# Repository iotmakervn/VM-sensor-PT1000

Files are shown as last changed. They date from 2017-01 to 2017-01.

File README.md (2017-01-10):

# VM-sensor-PT1000

## Hardware

### Schematics

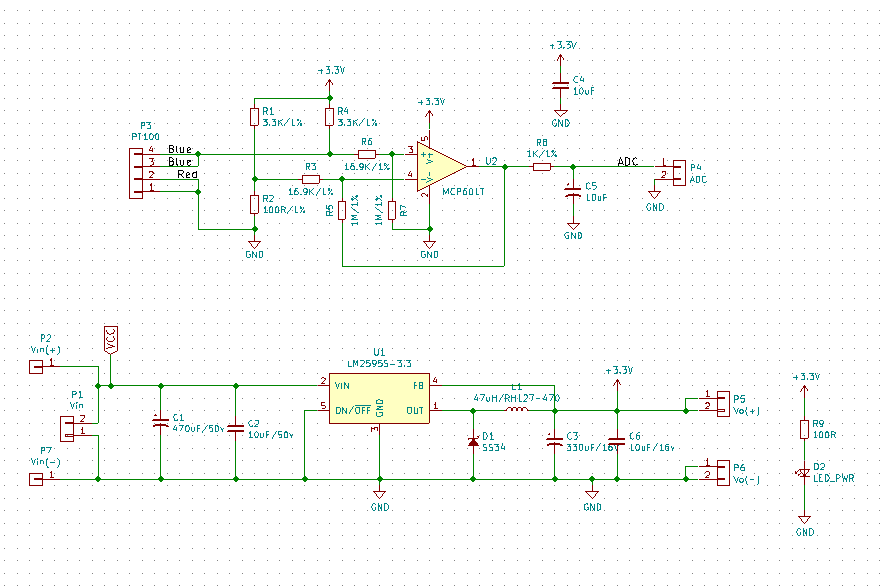
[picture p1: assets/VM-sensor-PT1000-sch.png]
VM-sensor-PT1000 Schematic


### PCB Layout

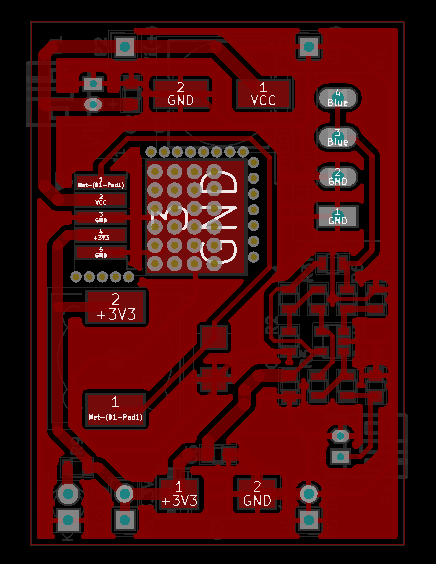
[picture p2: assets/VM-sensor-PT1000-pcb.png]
VM-sensor-PT1000 PCB


### 3D

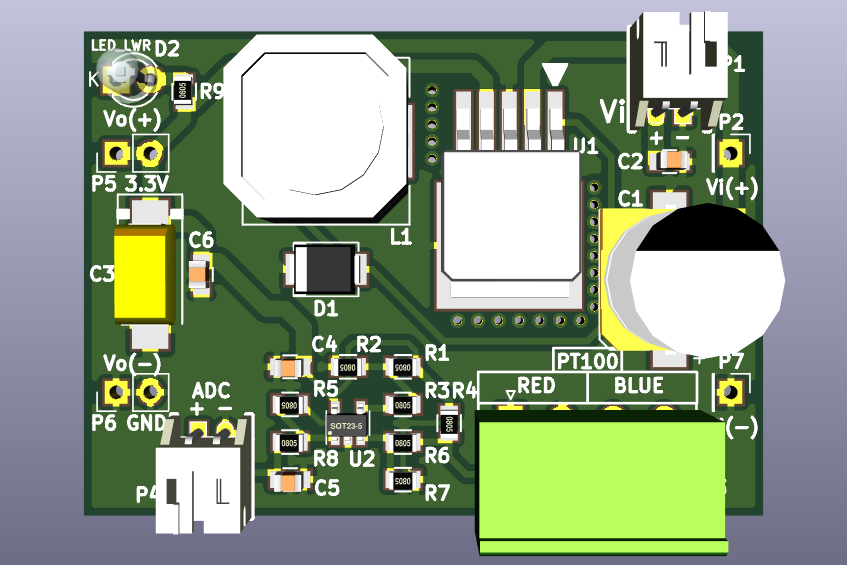
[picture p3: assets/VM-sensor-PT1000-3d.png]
VM-sensor-PT1000 3D


### Gerber

[Download](./assets/gerber.zip)

### BOM 
| Id | Designator  | Package | Quantity | Designation |
|----|---|---|---|---|
| 1  | U1 | TO-263-5Lead | 1 | LM2595S-3.3 |
| 2  | U2 | SOT-23-5 | 1 | MCP601T |
| 3  | D1 | do214aa-g | 1 | SS34 |
| 4  | D2 | LED-3MM | 1 | LED_Small |
| 5  | L1 | Choke_SMD_12x12mm_h8mm | 1 | 47uH/RH127-470 |
| 6  | C1 | c_elec_10x10.5 Aluminum | 1 | 470uF/50v |
| 7  | C3 | Tantalum_Case-D_EIA-7343-31_Hand | 1 | 330uF/16V |
| 8  | C4,C5,C6 | C_0805 | 3 | 10uF/16v |
| 9  | C2 | C_0805 | 1 | 10uF/50v |
| 10 | R1,R4 | R_0805 | 2 | 3.3K/1% |
| 11 | R2 | R_0805 | 1 | 100R/1% |
| 12 | R3,R6 | R_0805 | 2 | 16.9K/1% |
| 13 | R5,R7 | R_0805 | 2 | 1M/1% |
| 14 | R8 | R_0805 | 1 | 1K/1% |
| 15 | R9 | R_0805 | 1 | 100R |
| 16 | P3 | Domino-PT100.pretty | 1 | 4P-3.81 Pluggable Terminal Block |
| 17 | P2,P5,P6,P7 | Pin_Header_Straight_1x01_Pitch2.54mm | 4 | Male header, Pitch: 2.54MM |
| 18 | P4,P1 | s2b-ph-kl | 2 | WB2F-L40P2.54 |

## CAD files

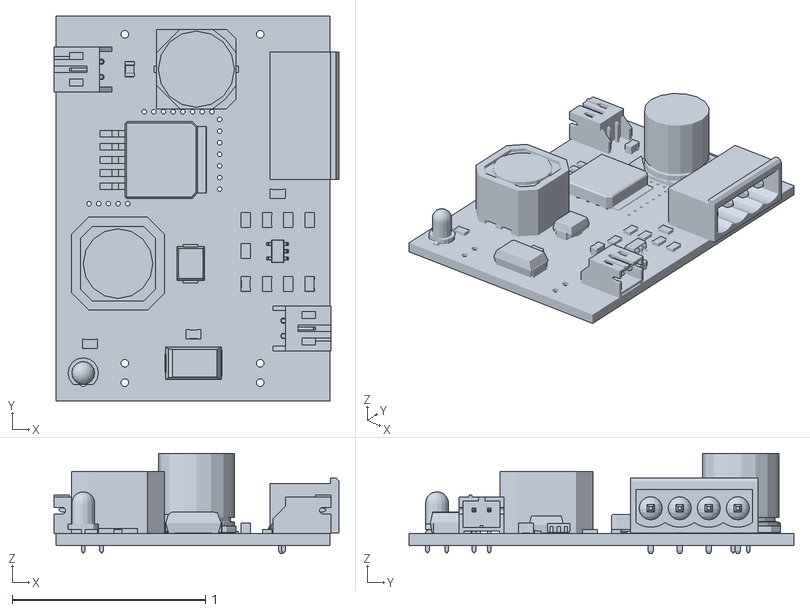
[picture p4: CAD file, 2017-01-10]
assets/VM-sensor-PT1000-3d.stl
1.47 x 1.99 x 0.517

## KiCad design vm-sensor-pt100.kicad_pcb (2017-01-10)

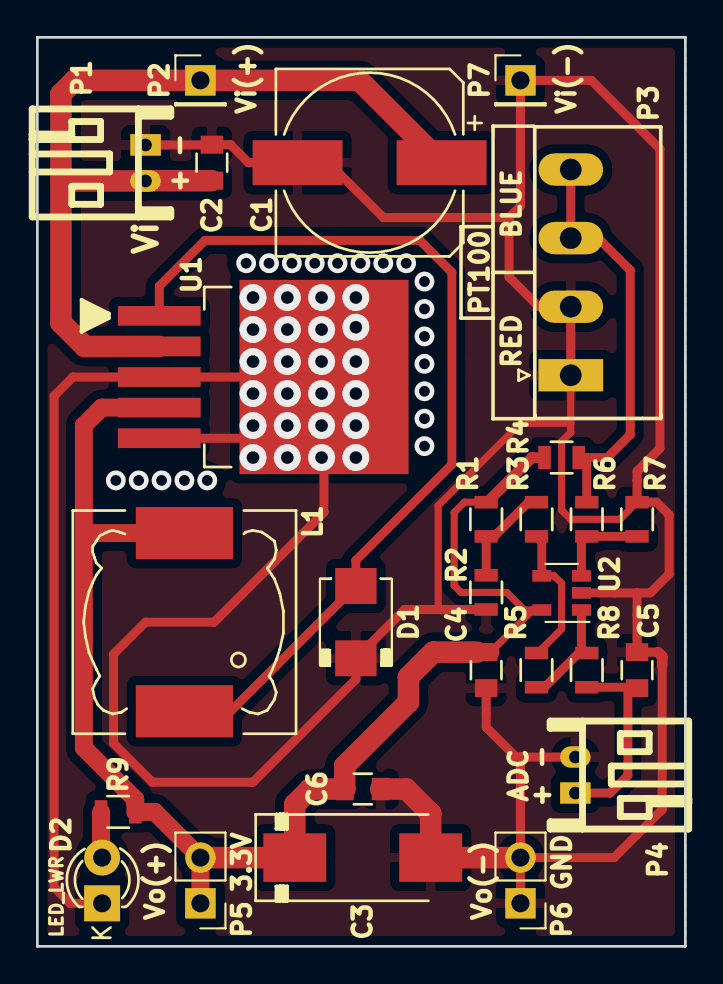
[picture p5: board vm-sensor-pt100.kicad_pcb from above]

Board: 2 copper layers, 36.0 x 50.5 mm, 27 parts (0 on the bottom side), 11 nets.

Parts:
C1: 470uF/50v; c_elec_10x10.5
C2, C6: 10uF/16v; C_0805
C3: 330uF/16V; Tantalum_Case-D_EIA-7343-31_Hand
C4, C5: 10uF; C_0805
D1: SS34; do214aa-g
D2: LED_Small; LED-3MM
L1: 47uH/RH127-470; Choke_SMD_12x12mm_h8mm
P1: Vi; s2b-ph-kl
P2: Vin(+); Pin_Header_Straight_1x01_Pitch2.54mm
P3: PT100; Domino-PT100.pretty
P4: ADC; s2b-ph-kl
P5: Vo(+); Pin_Header_Straight_1x02_Pitch2.54mm
P6: Vo(-); Pin_Header_Straight_1x02_Pitch2.54mm
P7: Vin(-); Pin_Header_Straight_1x01_Pitch2.54mm
R1, R4: 3.3K/1%; R_0805
R2: 100R/1%; R_0805
R3, R6: 16.9K/1%; R_0805
R5, R7: 1M/1%; R_0805
R8: 1K/1%; R_0805
R9: 100R; R_0805
U1: LM2595S-3.3; TO-263-5Lead
U2: MCP601T; SOT-23-5

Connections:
+3V3: C3.1, C4.1, C6.1, L1.2, P5.1, P5.2, R1.1, R4.1, R9.1, U1.4, U2.5
/ADC: C5.1, P4.1, R8.1
/Blue: P3.3, P3.4, R4.2, R6.2
GND: C1.2, C2.2, C3.2, C4.2, C5.2, C6.2, D1.2, D2.1, P1.1, P3.1, P3.2, P4.2, P6.1, P6.2, P7.1, R2.2, R7.1, U1.3, U1.5, U2.2
unnamed: D1.1, L1.1, U1.1
unnamed: D2.2, R9.2
unnamed: R1.2, R2.1, R3.2
unnamed: R3.1, R5.1, U2.4
unnamed: R5.2, R8.2, U2.1
unnamed: R6.1, R7.2, U2.3
VCC: C1.1, C2.1, P1.2, P2.1, U1.2

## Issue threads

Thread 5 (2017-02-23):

Bảng thử nghiệm tính nhiệt độ

trinhduc, 2017-02-23:
Chỉnh sửa mạch đo từ - 40°C đến +70°C, các thông số thử nghiệm được lưu ở https://docs.google.com/spreadsheets/d/1_OC6LajLobvM4PdVdACWSBcJOIMyyrFxt-WiPYZG23E/edit?ts=58ac17eb#gid=0
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

Thứ tự các linh kiện như trong hình trên và thay đổi

- R3, R6 : thay đổi từ 16k69 xuống còn 12k (linhkiện 0805, 1%)
- R2 : từ 100R xuống 91R (linh kiện 0805, 5%)
- R5 : từ 1M ohm xuống 333K3 (chồng 3 điện trở 1M ohm, linh kiện 0805, 1%)
- R1, R4 : 1K (linh kiện 0805, 1%)

Kết quả thay các linh kiện trên : đo được -54.624°C đến +74.876°C

Với biểu thức : Vx= 0.038*t +2.109

Một số lưu ý :

- CẦN CÓ PHẦN BẢO VỆ NGƯỢC NGUỒN CUNG CẤP - thêm diode trước pin Vin+

Closed 2017-02-23.

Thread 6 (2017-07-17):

Chỉnh sửa khoản giá trị đo từ - 40°C đến +70°C

trinhduc, 2017-07-17:
Chỉnh sửa mạch đo từ - 40°C đến +70°C, các thông số thử nghiệm được lưu ở
https://docs.google.com/spreadsheets/d/1_OC6LajLobvM4PdVdACWSBcJOIMyyrFxt-WiPYZG23E/edit?ts=58ac17eb#gid=0

> https://github.com/trinhduc/VM-sensor-PT1000/blob/master/assets/VM-sensor-PT1000-sch.png

Thứ tự các linh kiện như trong link trên và thay đổi
- R3, R6 :  thay đổi từ 16k69 xuống còn 12k (linhkiện 0805, 1%)
- R2 : từ 100R xuống 91R (linh kiện 0805, 5%)
- R5 : từ 1M ohm xuống 333K3 (chồng 3 điện trở 1M ohm, linh kiện 0805, 1%)
- R1, R4 : 1K (linh kiện 0805, 1%)

Kết quả thay các linh kiện trên : đo được -54.624°C đến +74.876°C
- [ ] Với biểu thức : Vx= 0.038*t +2.109

Một số lưu ý :
- CẦN CÓ PHẦN BẢO VỆ NGƯỢC NGUỒN CUNG CẤP - thêm diode trước pin Vin+

tuanpmt, 2017-07-17:
move dự án này vào internal giùm a

Closed 2017-07-17.

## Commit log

2016-12-24 add schematic & PCB
    [VM-sensor-PT1000.kicad_pcb, VM-sensor-PT1000.sch]
2016-12-26 change component 0603 to 0805 & header
    [VM-sensor-PT1000.kicad_pcb, VM-sensor-PT1000.sch]
2016-12-26 Completed PCB
    [VM-sensor-PT1000.kicad_pcb, VM-sensor-PT1000.sch]
2016-12-26 add assets folder
    [VM-sensor-PT1000-3d.stl, VM-sensor-PT1000.kicad_pcb, VM-sensor-PT1000.sch]
2017-01-06 Fix value resistor R3,R6, R7, R5 & symbol R2
    [VM-sensor-PT1000.kicad_pcb, VM-sensor-PT1000.sch]
2017-01-06 add led PWR & change header ADC
    [VM-sensor-PT1000.kicad_pcb, VM-sensor-PT1000.sch]
2017-01-07 completed new PCB design
    [VM-sensor-PT1000-3d.stl, VM-sensor-PT1000.kicad_pcb, VM-sensor-PT1000.sch]
2017-01-07 fix image PCB
2017-01-10 Final PCB
    [VM-sensor-PT1000-3d.stl, VM-sensor-PT1000.kicad_pcb, VM-sensor-PT1000.sch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]
2017-01-10 remove lib AMS1117
    [vm-sensor-pt100-B.Mask.gbs, vm-sensor-pt100-B.SilkS.gbo]
